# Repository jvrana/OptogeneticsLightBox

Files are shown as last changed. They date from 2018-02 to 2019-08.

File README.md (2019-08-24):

# Optogenetics Light Box
A programmable light delivery box for optogenetics experiments. This small and cheap light delivery system was used in several publications [<sup>1,2,3,4,5,6</sup>](#references). Making something that flashes light isn't rocket science, but its important to have a robust, and hardy system for delivering light in a reliable and reproducible way while doing long and expensive optogenetics experiments. Additionally, not having tools for light delivery can be a major roadblock for those new to optogenetics.

**Optogenetics?** - Broadly, optogenetics is the process of delivering light to cells to control function, often using engineered genetic constructs. Light offers several advantages over using chemicals for controlling cell behavior including spatio-temporal control, being basically free and limitless, and having minimal biological side effects. With light you can induce gene expression, stop gene expression, degrade proteins, initiate protein-protein interactions, activate neurons, and much more.

**What is it?** - This light box delivers programmed *doses* of light and determined intervals. It has three independent outputs than can be programmed independently via a LCD screen. Useful assuming if you want to do some controls or comparisons, this feature is useful. You can program the timing, interval, intensity, etc. for each LED output.

### Features:

* three independent programmable LED outputs
    * program pulse length, interval, intensity
* powerful 700mA LEDs
* LCD screen
* swap out LED formats (4X3, 3X1 arrays, etc.)
   * evenly target 12-well dishes for miscroscopy experiments (4x3)
   * deliver light to yeast plates (3x1)
* swap out LED colors (blue, red, etc.)

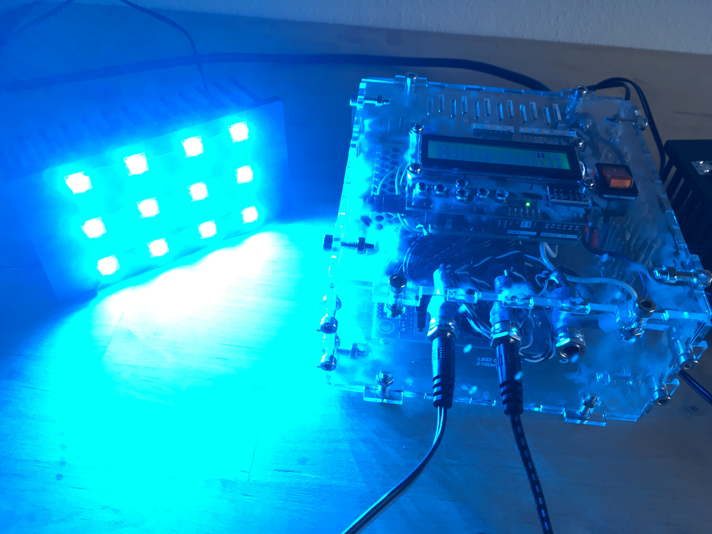
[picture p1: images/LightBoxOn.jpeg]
LightBoxOn


## Repo Contents
* [Arduino code](src/LEDProgrammer_V2-32.ino)
* [Laser cutter files](design/lasercutter)
* [Materials list](design/LEDControllerPartsList.xlsx)
* [Gallery](Gallery.md)

## Using the Light Box:

**Changing cell shape using light.** Proteins involved with
actin polymerization (SH3) were fused to a mutant plant protein that
clusters in reponse to blue light. Constructs were transfected into monkey cells
and ths Light Box was used to pulse blue light with the hypothesis that clustering
SH3 domains would recruit other proteins involved with actin polymerization and disrupt
the surrounding cytoskeleton. The figure below demonstrates this and shows that, as
a result, we can also alter cell shape using light.

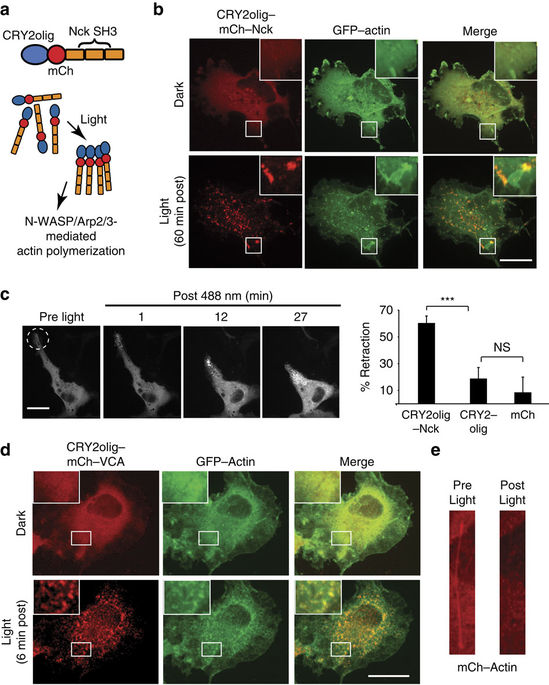
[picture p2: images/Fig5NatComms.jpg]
Light mediated cytoskeleton disruption


[Taslimi, A., Vrana, J. D., et al. An optimized optogenetic clustering tool for probing protein interaction and function. Nature communications 5, 4925 (2014).](https://www.nature.com/articles/ncomms5925)

a) Strategy for clustering Nck SH3 domains. (b) Cells expressing
CRY2olig–mCh–Nck and GFP–actin in dark, or 60 min post blue light
(500 ms pulse, 488 nm, every 3 min). Scale bar, 20 μm. (c) Local
photostimulation (within circle) of COS-7 cell expressing CRY2olig–mCh–Nck
results in retraction of cell extension. Graph at right shows
quantification of retraction (average and s.e.m., n=16) in cells
 expressing CRY2olig–mCh–Nck, or controls CRY2olig–mCh or mCherryN1
  45 min post initial light exposure. ***P<0.001. NS, not significant.
  (d) Cells expressing CRY2olig–mCh–VCA, CRY2olig and GFP–actin in
  dark or 6 min post blue light (500 ms pulse, 488 nm, every 3 min).
  Inset images at right show detail within white square. Scale bar,
  20 μm. (e) Stress fibres within cells expressing CRY2olig–GFP–VCA,
  CRY2olig and mCherry–actin are disrupted with light exposure.

## How to Get/Build One

If you'd like to build one yourself, create an **issue** on this repo (or **star** or **watch it**) so I can gauge interest and I can spend the time to put up instructions.

If you'd like to purchase one of these, please contact me. I've been commissed to build these for others before,
so let me know if you'd like one. The overall cost for commissioning me to build one averages ~$500 (50% material, 50% labor), with the main material cost being the cost is the LEDs, which can be quite expensive. The design is robust and
previous builds have all latest multiple years in the lab with no issues.

## Gallery

### Top

Demonstrating the input LCD screen. Its pretty straight forward. You can select the output (1, 2, or 3) and the light delivery characteristics (interval, pulse length, pulse intensity). The screen will also disply how long the program has been running for.

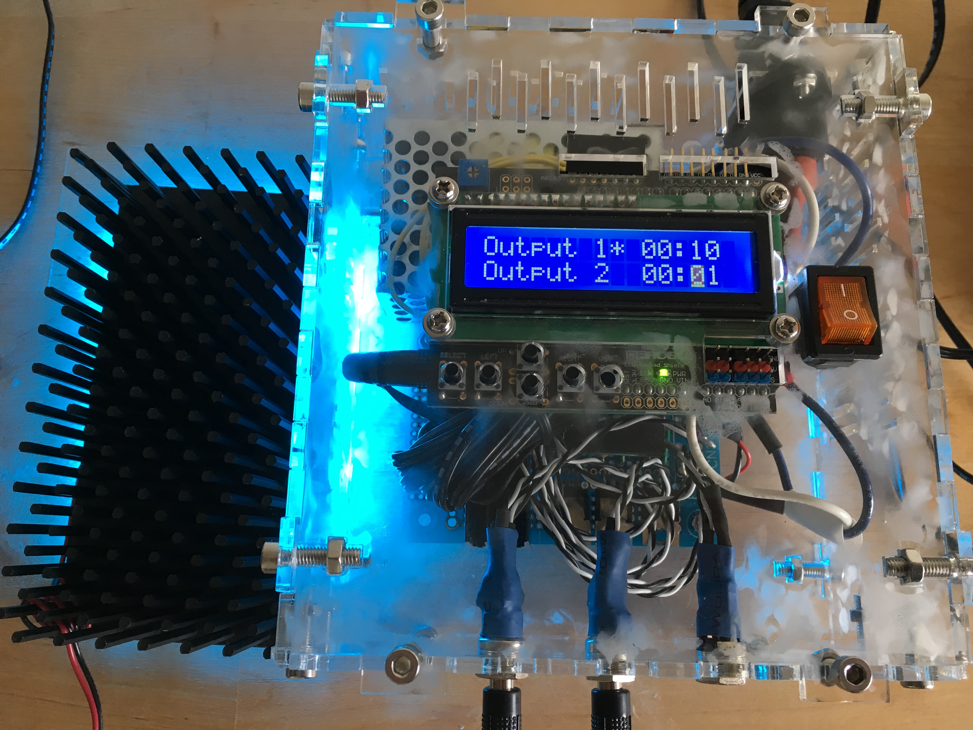
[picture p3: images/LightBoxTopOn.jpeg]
LightBoxTopOn


### Front

Up to three sets of LED arrays can be plugged into the front panel. Outputs are driven by a LED driver and support a variety of formats (4x3, 3x1, etc.).

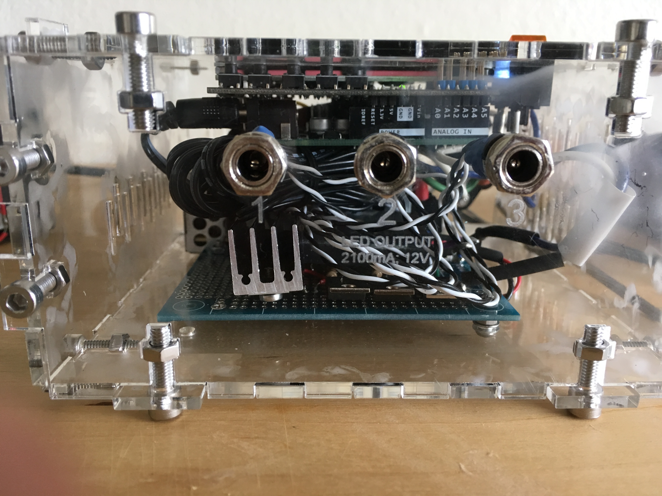
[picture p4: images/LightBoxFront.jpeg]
LightBoxFront


### Side

Hole for plugging in the Arduino USB-C cable. Ventilation on the other side.

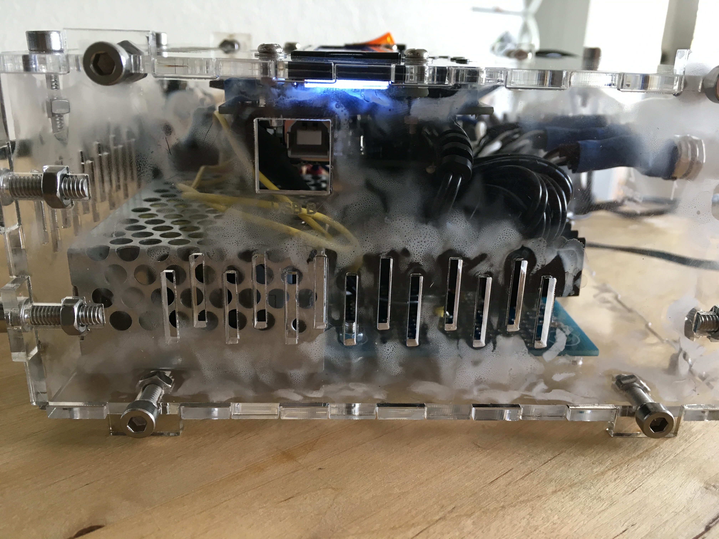
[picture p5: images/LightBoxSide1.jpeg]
LightBoxSide1

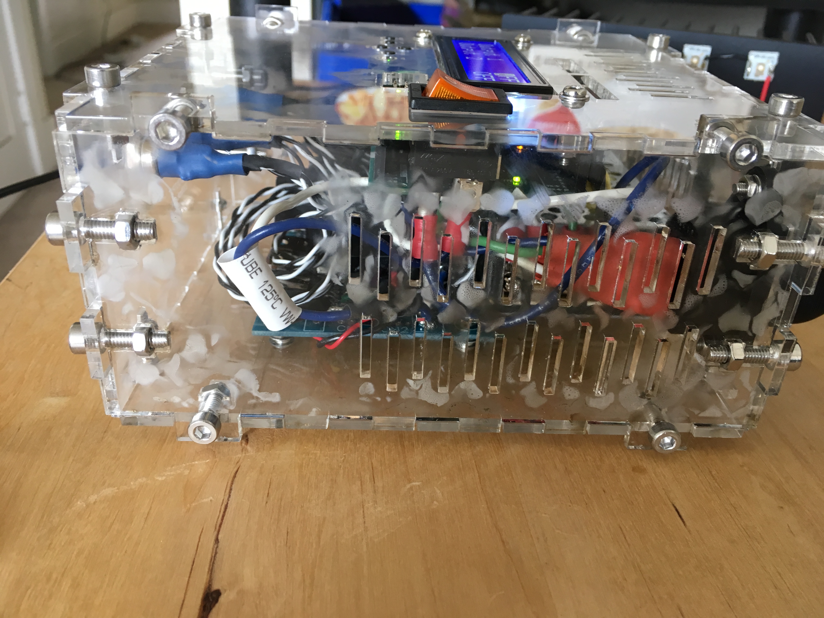
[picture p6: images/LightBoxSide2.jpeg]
LightBoxSide2


### Back

Nothing really interesting here...

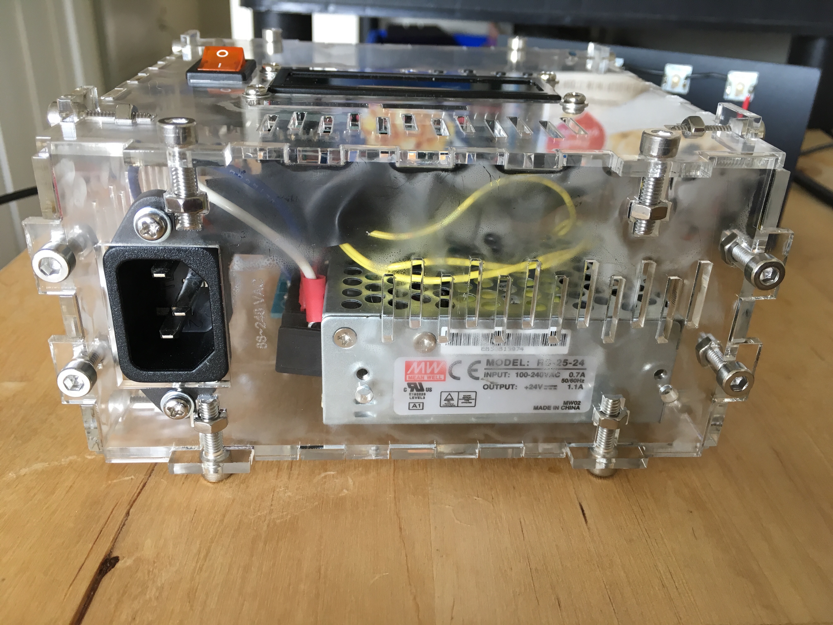
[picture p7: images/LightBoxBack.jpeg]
LightBoxBack


# References

Here are several papers that have used this design...

1. [Pathak, G. P. et al. Bidirectional approaches for optogenetic regulation of gene expression in mammalian cells using Arabidopsis cryptochrome 2. Nucleic Acids Res. 45, e167 (2017).](https://academic.oup.com/nar/article/45/20/e167/3744534)
2. [Taslimi, A. et al. Optimized second-generation CRY2-CIB dimerizers and photoactivatable Cre recombinase. Nat. Chem. Biol. 12, 425–30 (2016).](https://www.nature.com/articles/nchembio.2063)
3. [Taslimi, A., Vrana, J. D., et al. An optimized optogenetic clustering tool for probing protein interaction and function. Nature communications 5, 4925 (2014).](https://www.nature.com/articles/ncomms5925)
4. [Pathak, G. P., Strickland, D., Vrana, J. D. & Tucker, C. L. Benchmarking of optical dimerizer systems. ACS Synth Biol 3, 832–8 (2014).](https://pubs.acs.org/doi/10.1021/sb500291r)
5. [Hughes, R. M., Vrana, J. D., Song, J. & Tucker, C. L. Light-dependent, Dark-promoted Interaction between Arabidopsis Cryptochrome 1 and Phytochrome B Proteins. Journal of Biological Chemistry 287, 22165–22172 (2013).](http://www.jbc.org/content/287/26/22165.long)
6. Tucker, C. L., Vrana, J. D. & Kennedy, M. J. in Current protocols in cell biology / editorial board, Juan S. Bonifacino ... [et al.] 64, 17.16.1–20 (Current protocols in cell biology / editorial board, Juan S. Bonifacino ... [et al.], 2014).

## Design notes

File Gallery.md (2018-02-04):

# Gallery

## Top
LightBoxTopOn
LightBoxOn

## Front
LightBoxFront

## Side
LightBoxSide1
LightBoxSide2

## Back
LightBoxBack

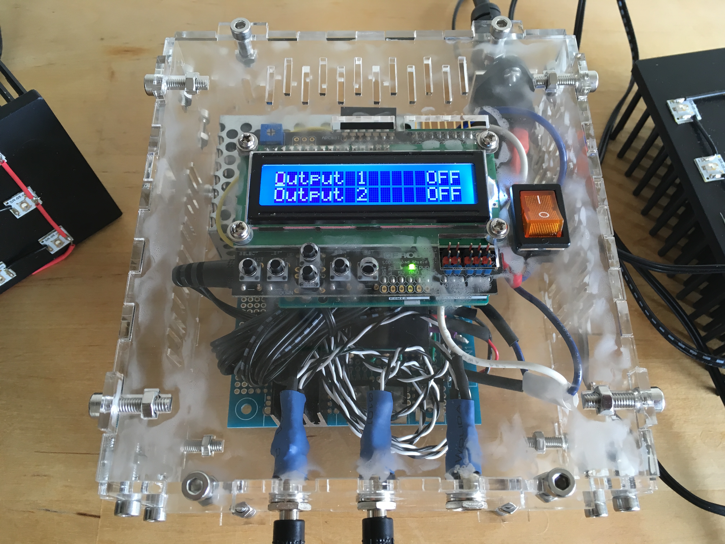
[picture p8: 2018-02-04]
images/LightBoxTop.jpeg

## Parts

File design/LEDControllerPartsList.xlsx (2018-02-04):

Item | Cost | Quantity | Vendor | Part # | Total
Arduino Uno R3 DIP Edition (Revision 3) (http://www.jameco.com/webapp/wcs/stores/servlet/Product_10001_10001_2151486_-1) | 29.95 | 1 | Jameco | 2151486 | 29.95
DFRobot LCD Shield for Arduino (http://www.jameco.com/webapp/wcs/stores/servlet/Product_10001_10001_2144411_-1) | 16.95 | 1 | Jameco | 2144411 | 16.95
Soldering iron and solder | 0 | 1 |  |  | 0
Standard 22 AWG hook up wire | 0 | 1 |  |  | 0
2100-mA BuckBlock Luxdrive LED Driver (LEDdynamics) | 19.99 | 1 | Luxeon Star |  | 19.99
Transistor Darlington NPN 60 Volt 5 Amp 3-Pin 3+ Tab TO-220 AmpB Rail | 0.39 | 5 | Jameco | 32993 | 1.95
Resistor Carbon Film 330 Ohm 1/2 Watt 5% (In Bags of 10 and 100) (http://www.jameco.com/webapp/wcs/stores/servlet/Product_10001_10001_661386_-1) | 0.099 | 10 | Jameco | 661386 | 0.99
130 × 70−mm rectangular heat sink with hex pin rated to 1.5-3°C/W | 27.88 | 2 | Luxeon Star |  | 55.76
Thermal epoxy or thermal tape | 3.34 | 3 | Luxeon Star |  | 10.02
470-nm Rebel LEDs, mounted on a 10 mm base (Luxeon Star LEDs) | 7.73 | 26 | Luxeon Star |  | 200.98
Arduino software (http://www.arduino.cc) | 0 | 1 | Arduino |  | 0
Speedy ABS Plastic Enclosure Box 4.9" x 2.5" x 1.5" | 3.95 | 1 | Jameco | 18914 | 3.95
PT Series Prototyping Board 3 Power Buses 3.5" x 2.5" | 9.95 | 1 | Jameco | 645677 | 9.95
Heat Shrink Tubing Fit-221B-1/8-Black 4 Feet Black Polyolefin Tubing (http://www.jameco.com/webapp/wcs/stores/servlet/Product_10001_10001_419160_-1) | 1.39 | 1 | Jameco | 419160 | 1.39
Heat Shrink Tubing Fit-221B-1/16-Black 4 Feet Black Polyolefin (http://www.jameco.com/webapp/wcs/stores/servlet/Product_10001_10001_419127_-1) | 1.19 | 1 | Jameco | 419127 | 1.19
Heat Shrink Tubing Fit-221B-1/4-Black 4 Feet Black Polyolefin Tubing (http://www.jameco.com/webapp/wcs/stores/servlet/Product_10001_10001_419207_-1) | 1.89 | 1 | Jameco | 419207 | 1.89
Acrylic Base Plate for Arduino and Breadboard (http://www.jameco.com/webapp/wcs/stores/servlet/Product_10001_10001_2237554_-1) | 3.95 | 1 | Jameco | 2237554 | 3.95
Connector Unshrouded Header 40 Position 2.54mm Straight Thru-Hole (http://www.jameco.com/webapp/wcs/stores/servlet/Product_10001_10001_160882_-1) | 0.79 | 2 | Jameco | 160882 | 1.58
AC to DC Power Supply Wall Adapter Transformer Single Output 15 Volt 1.6 Amp 24 Watt | 13.49 | 1 | Jameco | 2101702 | 13.49
24 AWG Black/White Stranded Twisted Pair Hook-Up Wire 100 Feet | 9.95 | 1 | Jameco | 173164 | 9.95
DC Power Jack Male 2.1mm 2 Position (http://www.jameco.com/webapp/wcs/stores/servlet/Product_10001_10001_151555_-1) | 1.75 | 4 | Jameco | 151555 | 7
2.1mm DC Power Plug to Pigtail Wires 6 Feet (http://www.jameco.com/webapp/wcs/stores/servlet/Product_10001_10001_2096763_-1) | 1.95 | 3 |  |  | 5.85
Shipping Costs | ?
 |  |  |  | Total | 396.78

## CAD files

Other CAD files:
design/lasercutter/LCDKeypadShieldLayout.dwg
design/lasercutter/LCDKeypadShieldLayout_20160706_PreppedForLaserCutter5.dwg
design/lasercutter/LCDKeypadEnclosure_PREPPEDFORCUTTER.dwg
design/lasercutter/LCDKeypadEnclosure_PREPPEDFORCUTTER.3dm

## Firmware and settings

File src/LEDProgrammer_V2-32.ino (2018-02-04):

/*
 @author: Justin D Vrana
 @version v2.32
 @since 2014-04-03

What is this?
The basic code needed to control a multi-output, programmable LED light device for optogenetic applications.
The the code allows for user-defined parameters to alter duration and intensity of light pulses at regular intervals.
Central to the device is an inexpensive microcontroller and LCD keypad to display and read user input to control
the duration and intensity of LED light pulses at user-defined intervals. Up to three LED outputs can be independently
programmed and different LED modules can be interchanged.

Usage:
Upload to Arduino Uno via USB. If uploaded properly, "Starting" should display on the LCD display screen and then the main page should display.
If there are issue uploading to the Arduino Uno, consult the Arduino website for help.

    To turn an output ON or OFF: From the main page on the LCD display, use the UP and DOWN buttons to select an output (indicated by a cursor)
    to edit. Move the cursor to the right using the RIGHT button and use either the UP or DOWN button to turn the output program ON
    or OFF. A countdown timer which counts down untill the next time the LED is to flash will display when the output program is running.

    To change an output's scheduled flashing: To change an output program, push SELECT to select the output highlighted by the cursor.
    Use the UP and DOWN buttons to select and attribute to edit. To edit and attribute, move the cursor to the right using the RIGHT
    button and then hold the UP or DOWN button to increase or decease a value. Move the cursor back to the left using the LEFT button
    to change attributes to edit. Push the SELECT button at any time to return to the main page.

Sources:
- The original "LiquidCrystal" 8-bit library and tutorial
    http://www.arduino.cc/en/uploads/Tutorial/LiquidCrystal.zip
    http://www.arduino.cc/en/Tutorial/LCDLibrary

Tested only with a Arduino Uno (http://arduino.cc/) and DFRobot Keypad Shield (http://dfrobot.com)

*****Important*****:
Check and change "User Defined Paramters" directly below if needed. LCD pins, output pins, and anaolog voltages
must be changed if using an LCD Keypad Shield other than the DFRobot Keypad Shield or SainSmart Keypad Shield.
Refer to the datasheet of the LCD Keypad Shield to determine correct parameter values.
Button values can be reset for using the "Button Reset Mode"

Button Reset Mode:
If using a different LCD Keypad shield, button values may need to be reset. To initiate button reset mode, during startup hold
down any button and continue holding button for at least three seconds when prompted. Follow the on screen instructions.
The screen will request you press and hold each button while it records the voltage values associated with that button.
Once completed, voltage values will be stored to the Arduino's EEPROM memory. Upon each start-up, these voltage values
will be loaded and used. To reset button values on the Arduino, simply re-upload this program using the "UPLOAD" button.

V 2.0 - New Version with new interface
V 2.1 - Re-vamped interface
V 2.2 - Expanded to three outputs
V2.3 - Created button reset mode
V2.32 (4/10/14) - Corrected coding error, cast timers to int instead of long
*/








////////////////////////////////////////////////////////////
////////////////////////////////////////////////////////////
/////////////////// User Defined Parameters ////////////////
////////////////////////////////////////////////////////////
////////////////////////////////////////////////////////////

/*/////////////////// User Defined LCD Display Parameters ////////////////////
// Check LCD Keypad Shield datasheet to determine which Arduino Uno pins correspond
// to the RS, Enable, D4, D5, D6, and D7 pins on the LCD Keypad Shield. Change the
// values below. For example, DFRobot Keypad Shield for Arduino designates:
//    Digital Pin 9 on the Arduino to the reset pin (RS) on the LCD Keypad
//    Digital Pin 8 on the Arduino Uno to the Enable pin on the LCD keypad
//    Digital Pin 4 on the Arduino Uno to the D4 pin on the LCD keypad shield
//    Digital Pin 5 on the Arduino Uno to the D5 pin on the LCD keypad shield
//    Digital Pin 6 on the Arduino Uno to the D6 pin on the LCD keypad shield
//    Digital Pin 7 on the Arduino Uno to the D7 pin on the LCD keypad shield
//    Analog Pin 0 on the Arduino Uno to the Button select pin on the LCD keypad shield
///////////////////////////////////////////////////////////////////////////////*/
int RS_pin = 8;
int enable_pin = 9;
int D4_pin = 4;
int D5_pin = 5;
int D6_pin = 6;
int D7_pin = 7;
int button_select_pin = 0;


/*//////////////////// User Defined LCD Display Parameters ////////////////////
// Check LCD Keypad Shield datasheet to determine which Arduino Uno pins are
// available for use as output pins. Pins designated to the RS, Enable, D4, D5,
// D6, D7, and Button select pins (see above) on the LCD Keypad shield are
// unavailable for use as LED output pins. For example, DFRobot Keypad Shield
// has pins 12, 11, and 3 pins free.
///////////////////////////////////////////////////////////////////////////////*/
int LED_output_pin_1 = 12;
int LED_output_pin_2 = 11;
int LED_output_pin_3 = 3;


/*//////////////////// User Defined Analog Button Parameters ////////////////////
// Buttons on the LCD Keypad Shield change the voltage to the button_select_pin.
// Different values being recorded correspond to which button is being pressed
// Depending on LCD Keypad shield, the following values may be different. Button
// values can be reset live if desired by pressing and holding any button for
// three seconds during startup.
///////////////////////////////////////////////////////////////////////////////*/

//DFRobot LCD Keypad Shield Values
int btnNONE_upper_voltage = 1000;
int btnRIGHT_upper_voltage = 0;
int btnUP_upper_voltage = 150;
int btnDOWN_upper_voltage = 330;
int btnLEFT_upper_voltage = 500;
int btnSELECT_upper_voltage = 750;
int button_threshold = 50;

/*
//SainSmart LCD Keypad Shield Values
int btnNONE_upper_voltage = 1023;
int btnRIGHT_upper_voltage = 0;
int btnUP_upper_voltage = 144;
int btnDOWN_upper_voltage = 329;
int btnLEFT_upper_voltage = 505;
int btnSELECT_upper_voltage = 742;
*/

////////////////////////////////////////////////////////////
////////////////////////////////////////////////////////////
/////////////// END User Defined Parameters ////////////////
////////////////////////////////////////////////////////////
////////////////////////////////////////////////////////////


////////////////////////////////////////////////////////////
////////////////////////////////////////////////////////////
///////////////////// VARIABLES ////////////////////////////
////////////////////////////////////////////////////////////
////////////////////////////////////////////////////////////

#include <LiquidCrystal.h>
#include <EEPROM.h>

LiquidCrystal lcd(RS_pin, enable_pin, D4_pin, D5_pin, D6_pin, D7_pin); // Used to display information to LCD Display.

///////////////////// struct output ////////////////////
// Defines LED output parameters
// Name: name of output
// pin: which pin controls this output
// runs_status: is this output program currently running?
// run_state: is the LED currently powered on?
// attributes: defines duration, interval, and intensity for this input
// attribute_labels: labels for interval, interval, and intensity
// interval_timer: counter used to determine when to power ON led (change state = true)
// duration_timer: counter used to determine when to power OFF led (change state = false)
///////////////////// END struct output ////////////////////
struct output{
  String name;
  int pin;
  boolean run_status;
  boolean run_state;
  int attributes[3];
  String attribute_labels[3];
  long interval_timer;
  long duration_timer;
} out_1, out_2, out_3; // define outputs 1, 2, and 3

int LED_output_pins[3] = {LED_output_pin_1, LED_output_pin_2, LED_output_pin_3}; // Designates output pins on Arduino used to control LED outputs
output LED_outputs[3] = {out_1, out_2, out_3}; // Array for each output. Index is used later in program to grab corresponding output.
int selected_item = 0; // Used to designate item highlighted on LCD Display.
int current_page = 0; // Current page beging viewed (0 = top, 1 = edit).
int selected_output = 0; // Designate last selected output. Index to determine which output structure to retrieve from "LED_outputs" array.
int top_item_displayed = 0; // Which item is displayed at top of page.
int cursorPositionY = 0; // Designates where the cursor should be (0=top row, 1=bottom row).
int cursorPositionX = 0; // Designates where the cursor should be (0=1st character, 1=12th character).
int lcd_key     = 0; // Analog input key pressed. Example: btnRIGHT = 0
int prev_lcd_key = 0; // Previous analog input key pressed.
// long button_hold_interval_counter: Used to increase or decrease a value while holding the UP or DOWN buttons.
// Designates total time since value was increased while holding button.
long button_hold_interval_counter = 0;
// long button_hold_start_counter: Used to increase or decrease a value while holding the UP or DOWN buttons.
// Designates total time button is held.
long button_hold_start_counter = 0;
int button_values[6] = {btnRIGHT_upper_voltage, btnUP_upper_voltage, btnDOWN_upper_voltage,
  btnLEFT_upper_voltage, btnSELECT_upper_voltage, btnNONE_upper_voltage}; //Contains voltage values for each button
String button_names[6] = {"RIGHT", "UP", "DOWN", "LEFT", "SELECT", "NONE"}; // Contains names for each button
int button_addresses[6] = {101, 102, 103, 104, 105, 106}; // Contains EEPROM address for each button value
byte button_override_true = 111; // Contains value to override button values (after button reset mode)
int button_override_address = 111; // Address of whether to overrid buttons



////////////////////////////////////////////////////////////
////////////////////////////////////////////////////////////
///////////////////// DEFINITIONS ////////////////////////////
////////////////////////////////////////////////////////////
////////////////////////////////////////////////////////////

// Definitions used to determine pages.
// Definitions used to determine button pushed on lcd keypad
#define EDITPAGE 1
#define TOPPAGE 0
#define btnRIGHT  0
#define btnUP     1
#define btnDOWN   2
#define btnLEFT   3
#define btnSELECT 4
#define btnNONE   5
#define btnOverride 111



///////////////////////////////////////////////////////////////////////////////
///////////////////////////////////////////////////////////////////////////////
///////////////////////////////////////////////////////////////////////////////
///////////////////////////////////////////////////////////////////////////////
/////////////////// MAIN METHODS (setup and loop //////////////////////////////
///////////////////////////////////////////////////////////////////////////////
///////////////////////////////////////////////////////////////////////////////
///////////////////////////////////////////////////////////////////////////////


///////////////////// method: setup() ////////////////////
// Method initializes upon Arduino Uno startup and
// initialized variables for LED_outputs and LCD display
// Returns: void
///////////////////// END Setup ////////////////////
void setup() {
  Serial.begin(9600);
  // Initialize output values for each LED output
  for (int i = 0; i < 3; i++) {
    LED_outputs[i].name = "Output ";
    LED_outputs[i].name = LED_outputs[i].name + (i + 1); // Name of this output to be displayed on the LCD display
    LED_outputs[i].pin = LED_output_pins[i]; // Designates this output to a pin on the Arduino Uno
    LED_outputs[i].run_status = false; // Determines if the output program is currently running (true) or not running (false)
    LED_outputs[i].run_state = false; // Determines if the LED is powered (true) or not powered (false)
    LED_outputs[i].attributes[0] = 1; // Value defines the duration of the LED light pulse
    LED_outputs[i].attributes[1] = 10; // Value defines the interval duration of the LED light pulse
    LED_outputs[i].attributes[2] = 100; // Value defines the intensity of the LED light pulse (0%-100%)
    LED_outputs[i].attribute_labels[0] = "Dura(s)"; // Corresponding label for duration to be displayed on the LCD display
    LED_outputs[i].attribute_labels[1] = "Int(s)"; // Corresponding label for interval to be displayed on the LCD display
    LED_outputs[i].attribute_labels[2] = "Intensity(%)"; // Corresponding label for intensity to be displayed on the LCD display
  }
  lcd.begin(16,2);
  lcd.print("Starting");
  delay(300);
  lcd.clear();
  lcd.print("Starting.");
  delay(300);
  lcd.clear();
  lcd.print("Starting..");
  delay(300);
  lcd.clear();
  lcd.print("Starting...");
  Serial.print("Checking for button reset mode\n");
  buttonReset(); // Check for button and activate button reset if needed.
  Serial.print("Loading values from memory\n");
  loadButtonValuesFromMemory(); // Only loads if button reset has been previously activated.
  delay(300);
  lcd.clear();
  lcd.blink(); // Sets cursor blinker ON
  lcd.cursor(); // Sets underline cursor ON
  printScreen();
  button_hold_interval_counter = millis();
}

///////////////////// method: loop() ////////////////////
// Method is automatically looped by the Arduino Uno microcontroller continuously
// returns: void
///////////////////// END loop() ////////////////////
void loop() {
  flash();
  printScreen();
  displayCursor();
  delay(50);
  lcd_key = read_LCD_buttons(); //Read analog input from buttons
  if (lcd_key != prev_lcd_key)  { //New key is pressed
     button_hold_start_counter = millis(); // Timer for how long button is held
     switch (lcd_key) {               // depending on which button was pushed, we perform an action

         case btnRIGHT:{
              if (cursorPositionX == 0) { cursorPositionX = 1; }
              delay(50);
              break;
         }
         case btnLEFT:{
               if (cursorPositionX == 1) {
                 cursorPositionX = 0;
               }
               break;
         }
         case btnUP:{
               if (cursorPositionX == 0) {
                 lcd.clear();
                 prevItem();
               }
               else if (cursorPositionX == 1 && current_page == TOPPAGE) {
                 if (LED_outputs[selected_item].run_status == false) {
                   turnOnOutput(selected_item);
                 } else {
                   turnOffOutput(selected_item);
                 }
               }
               lcd.clear();
               printScreen();
               break;
         }
         case btnDOWN:{
               if (cursorPositionX == 0) {
                 lcd.clear();
                 nextItem();
               }
               else if (cursorPositionX == 1 && current_page == TOPPAGE) {
                 if (LED_outputs[selected_item].run_status == false) {
                   turnOnOutput(selected_item);
                 } else {
                   turnOffOutput(selected_item);
                 }
               }
               lcd.clear();
               printScreen();
               break;
         }
         case btnSELECT:{
               if (current_page == TOPPAGE) {
                 selected_output = selected_item;
                 toEditPage();
               }
               else if (current_page == EDITPAGE) {
                 toTopPage();
               }
               break;
         }
         case btnNONE:{
               break;
         }
     }
   }
   // Else if on edit page, with cursor fartherest right and the UP or DOWN button is pressed
   else if (cursorPositionX == 1 && current_page == EDITPAGE && (lcd_key == btnDOWN || lcd_key == btnUP)) {
      int * value;
      value = &LED_outputs[selected_output].attributes[selected_item];
      increaseValueWhileHoldingButton(value); // Either increase or decease value of attribute while holding the UP or DOWN button
      lcd.clear(); // Clear screen
      printScreen(); // Print to screen
      delay(50);
   }
   prev_lcd_key = lcd_key; // Save previous key pressed
}

void turnOffOutput(int which_output) {
  LED_outputs[which_output].run_status = false;
  LED_outputs[which_output].run_state = false;
  LED_outputs[which_output].interval_timer = millis();
  LED_outputs[which_output].duration_timer = millis();
}

void turnOnOutput(int which_output) {
  LED_outputs[which_output].run_status = true;
  LED_outputs[which_output].run_state = true;
  LED_outputs[which_output].interval_timer = millis();
  LED_outputs[which_output].duration_timer = millis();
}

///////////////////// method: flash() ////////////////////
// Uses interval_timer and duration_timer of each output to determine when to
// power LEDs ON or OFF. Duration and interval attributes (attributes[0] and attributes[1] respectively)
// are used to determine the length of the duration and interval. Intensity (attribute[2]) is used to
// determine the how much power goes to the LEDs.
// returns: void
///////////////////// END flash()  ////////////////////
void flash() {
  for (int i = 0; i < 3; i++) {

    unsigned long current_time = millis();
    /*  //Serial output
    if (i == i) {
      Serial.print("Output: ");
      Serial.print(i);
      Serial.print( " Run Status: ");
      Serial.print(LED_outputs[i].run_status);
      Serial.print( " LED States: ");
      Serial.print(LED_outputs[i].run_state);
      Serial.print(" Current time: ");
      Serial.print(millis()/1000);
      Serial.print( " Interval Timer: ");
      Serial.print(LED_outputs[i].interval_timer/1000);
      Serial.print( " Duration Timer: ");
      Serial.print(LED_outputs[i].duration_timer/1000);
      Serial.print( " Interval: ");
      Serial.print(LED_outputs[i].attributes[1]);
      Serial.print( " Duration: ");
      Serial.print(LED_outputs[i].attributes[0]);
      Serial.print("  ");
      Serial.print(current_time - LED_outputs[i].interval_timer);
      Serial.print( " > " );
      unsigned long this_interval = LED_outputs[i].attributes[1] * 1000.0;
      Serial.print(this_interval);
      Serial.print("\n");
    }
    /**/
    if (LED_outputs[i].run_status) {
      boolean state = LED_outputs[i].run_state;
      if (current_time - LED_outputs[i].interval_timer > LED_outputs[i].attributes[1]*1000.0 && !state) {
          LED_outputs[i].run_state = true;
          LED_outputs[i].interval_timer = current_time; // reset interval timer
          LED_outputs[i].duration_timer = current_time; // reset duration timer
      }
      if (millis() - LED_outputs[i].duration_timer > LED_outputs[i].attributes[0] * 1000.0 && state) {
        LED_outputs[i].run_state = false;
        LED_outputs[i].duration_timer = current_time; // reset duration timer
      }
      if (LED_outputs[i].run_state) {
        analogWrite(LED_outputs[i].pin, map(LED_outputs[i].attributes[2], 0, 100, 0, 255));
      }
      else {
        digitalWrite(LED_outputs[i].pin, LOW);
      }
    }
    else {
      LED_outputs[i].interval_timer = current_time;
      LED_outputs[i].duration_timer = current_time;
      digitalWrite(LED_outputs[i].pin, LOW);
    }
  }
}



///////////////////////////////////////////////////////////////////////////////
///////////////////////////////////////////////////////////////////////////////
///////////////////////////////////////////////////////////////////////////////
///////////////////////////////////////////////////////////////////////////////
/////////////////// METHODS FOR USER DISPLAY AND INTERACTION //////////////////
///////////////////////////////////////////////////////////////////////////////
///////////////////////////////////////////////////////////////////////////////
///////////////////////////////////////////////////////////////////////////////


///////////////////// method: toTopPage() ////////////////////
// Simply returns to the first page to display the outputs.
// Text is scrolled left and cursor position is reset.
// returns: void
///////////////////// END toTopPage() ////////////////////
void toTopPage() {
  scrollText(false, 50, 16);
  lcd.clear();
  cursorPositionY = 0;
  cursorPositionX = 0;
  current_page = TOPPAGE;
  selected_item = 0;
  top_item_displayed = 0;
  printScreen();
}

///////////////////// method: toEditPage() ////////////////////
// Simply returns to the edit page to display the output attributes
// Text is scrolled right and cursor position is reset.
// returns: void
///////////////////// END toEditPage() ////////////////////
void toEditPage() {
  scrollText(true, 50, 16);
  lcd.clear();
  cursorPositionY = 0;
  cursorPositionX = 0;
  current_page = EDITPAGE;
  selected_item = 0;
  top_item_displayed = 0;
  printScreen();
}

///////////////////// method: display() ////////////////////
// Displays cursor at position as determined by cursorPositionX
// and cursorPositionY
// returns: void
///////////////////// END displayCursor() ////////////////////
void displayCursor() {
  if (cursorPositionY == 0 && cursorPositionX == 0) {
    lcd.setCursor(0,0);
  }
  else if (cursorPositionY == 1 && cursorPositionX == 0) {
    lcd.setCursor(0,1);
  }
   else if (cursorPositionY == 0 && cursorPositionX == 1) {
    lcd.setCursor(13,0);
  }
  else if (cursorPositionY == 1 && cursorPositionX == 1) {
    lcd.setCursor(13,1);
  }
}
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
